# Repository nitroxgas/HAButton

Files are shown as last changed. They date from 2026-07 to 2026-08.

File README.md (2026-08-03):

# HAButton

A quick project designed to repurpose used vapes into something useful: sending events to Home Assistant. It uses a small microcontroller powered by the vape's circuitry to monitor three mechanical switches. When one or more buttons are pressed, the device wakes up, connects to Wi-Fi, and publishes its status via MQTT. Home Assistant automatically recognizes the device and can be programmed to trigger automations based on the event data.
This is a quick weekend project—a first version with plenty of room for improvement.

**Docs:** [English](DOC/en/README.md) · [Português](DOC/README.md)

Build with Cursor, Grok-4.5 and PlatformIO - Firmware for **ESP32-C3 Super Mini**: 3 switches, awake session, MQTT gestures (Home Assistant), OTA, and LED effect pin.

--- 
<p align="center">
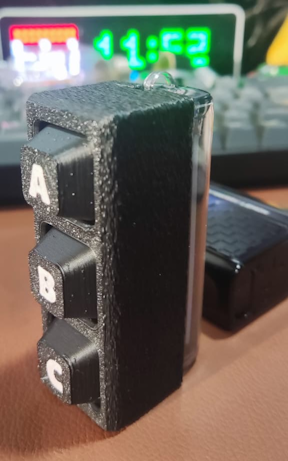
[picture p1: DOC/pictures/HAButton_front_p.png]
Front
  
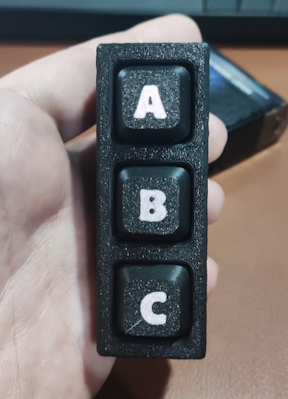
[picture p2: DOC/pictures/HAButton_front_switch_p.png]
Switchs
  
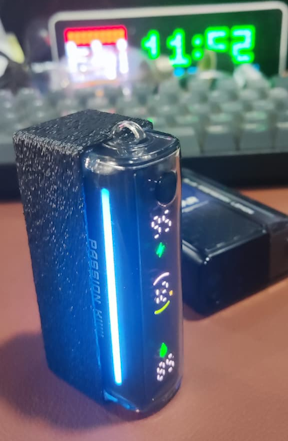
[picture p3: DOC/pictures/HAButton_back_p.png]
Back
  
</p>

## Quick start

```bash
pio run
pio run -t upload
pio device monitor
```

- Portal: hold **A+B+C ~10 s** → AP `HAButton-XXXX`
- Default idle: **20 s** (restarts on each gesture)
- OTA: [English](DOC/en/ota.md) · [Português](DOC/ota.md)
- Full documentation: [English](DOC/en/README.md) · [Português](DOC/README.md)

## Hardware (summary)

| Function | GPIO |
|---|---|
| Buttons A/B/C | 4 / 5 / 3 |
| Effect LED | 7 (PWM ~2.5 V) |
| Status LED | 8 |

Firmware version: **1.4.2** (`include/config.h`)
---
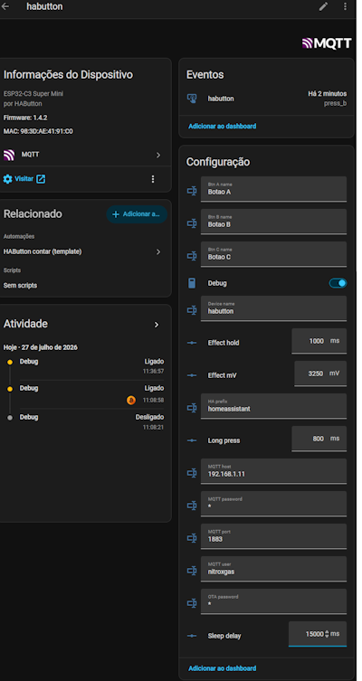
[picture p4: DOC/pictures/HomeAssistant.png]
Home Assistant

---

## Português

Firmware PlatformIO para **ESP32-C3 Super Mini**: 3 switches, sessão acordada, gestos MQTT (Home Assistant), OTA e pino de efeito LED.

Documentação completa: [DOC/README.md](DOC/README.md).

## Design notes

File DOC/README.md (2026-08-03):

# Documentação HAButton

**Idioma:** [Português](README.md) · [English](en/README.md)

Projeto rápido, feito para aproveitar vaporizadores usados, para algo útil - Enviar eventos para um Home Assistant; Ele usa um pequeno microcontrolador alimentado pelo circuito do vaporizador e monitora 3 switchs mecânicos. 
Quando pressionado um ou mais botões o dispositivo acorda, conecta no wifi e publica o estado em um MQTT; 
O Home Assistant por sua vez reconhece automaticamente este dispositivo e pode ser programado para fazer automações com as informações dos eventos; 

Projeto rápido de final de semana, primeira versão, ainda muito a melhorar; 

Faça um parecido para os vaporizadores que conseguir obter, melhor forma de reaproveitar o lixo eletrônico que eles produzem.

O projeto alimenta um ESP32-C3 com os fios destinados ao sensor de pressão do vape. Opcionalmente utiliza o fio de retorno do sensor para informar o uso ao vape, caso ele tenha algum display ou led de animação na sua estrutura.

Uso os GPIOs do ESP32-C3 que monitoram interrupção para tirar o dispositivo do estado de deepsleep e executar o envio de eventos via MQTT;

Para os switchs uso 3 mecanicos padrão;

No primeiro boot o dispositivo inicializa um Access Point para receber as primeiras configurações de wifi e etc. Após conectar no WIFI e publicar os dados no MQTT de um Home Assistant, as configurações podem ser realizadas diretamente na interface. 
Lembre-se que é necessário "acordar" o dispositivo para ele receber alterações de configuração via MQTT;

Atualização via OTA simples, para ser possível o desenvolvimento e implementação usando a alimentação via vape. 

### **NUNCA LIGUE NA USB COM A ALIMENTAÇÃO PELA BATERIA DO VAPE JÁ INSTALADA, PODE DANIFICAR SEU USB**;

Você vai precisar:
 Vape usado e desmontado. **Cuidado neste processo de desmontagem, recomendo uso de luvas e óculos de proteção e descarte imediato dos componentes umidos, contém nicotina que irrita a pele e etc.** Neste caso usei um G30k-Pro, mas quase todos funcionam da mesma forma, lendo um sensor de pressão e alimentando resistências para gerar vapor;
 ESP32-C3 Super Mini;
 3 Switchs mecanicos, ou qualquer outro botão que tiver disponível;
 Fios e etc para as ligações;
 E um case, neste caso modelei um simples e imprimi em 3D; Disponível em: [MakerWorld](https://makerworld.com/en/models/3101722-habutton-g30kpro-case#profileId-3496295) ou [.3mf Neste Repositório](../DOC/pictures/habutton_G30kpro.3mf)

==Projeto feito usando Cursor e Grok-4.5 High Fast;== Sim, porque é um projeto rápido e IA é ótima para isto atualmente;

## Objetivo

Dispositivo com bateria e botões: acorda, mantém sessão (idle 20 s), publica gestos MQTT com discovery HA, OTA na LAN, efeito PWM no GPIO7 durante o envio, e volta ao deep sleep.

| Documento | Conteúdo |
|---|---|
| [arquitetura.md](arquitetura.md) | Sessão acordada, módulos, MQTT |
| [hardware.md](hardware.md) | Pinout A/B/C, efeito GPIO7, portal |
| [configuracao.md](configuracao.md) | Portal, sleep 20s, event_types |
| [mqtt-topicos.md](mqtt-topicos.md) | Todos os tópicos MQTT (runtime + discovery) |
| [mqtt-config.md](mqtt-config.md) | Debug logs + config remota via MQTT/HA |
| [homeassistant-contadores.md](homeassistant-contadores.md) | Contadores/automações: UI ou packages YAML |
| [homeassistant-fallback-yaml.md](homeassistant-fallback-yaml.md) | YAML se discovery falhar |
| [desenvolvimento.md](desenvolvimento.md) | Build USB e overview |
| [ota.md](ota.md) | Guia completo de update OTA |

Home Assistant

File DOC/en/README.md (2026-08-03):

# HAButton Documentation (English)

**Language:** [English](README.md) · [Português](../README.md)

A quick project designed to repurpose used vapes into something useful: sending events to Home Assistant. It uses a small microcontroller powered by the vape's circuitry to monitor three mechanical switches. 
When one or more buttons are pressed, the device wakes up, connects to Wi-Fi, and publishes its status via MQTT. 
Home Assistant automatically recognizes the device and can be programmed to trigger automations based on the event data.

This is a quick weekend project—a first version with plenty of room for improvement.

Build a similar one with whatever vapes you can get your hands on; it’s a great way to repurpose the electronic waste they generate.

The project powers an ESP32-C3 using the wires originally intended for the vape's pressure sensor. 
Optionally, it uses the sensor's return wire to signal usage to the vape itself, in case the unit has a display or animated LED.
I use the ESP32-C3's GPIOs configured for interrupts to wake the device from deep sleep and send events via MQTT.
For the switches, I use three standard mechanical ones.
On the first boot, the device starts an Access Point to receive initial Wi-Fi settings and other configurations. Once connected to Wi-Fi and publishing data to Home Assistant via MQTT, settings can be adjusted directly through the interface. 
It supports simple OTA updates, allowing for development and deployment while powered by the vape. 
**Remember, you must "wake up" the device for it to receive configuration changes via MQTT or OTA.**

### **NEVER CONNECT THE USB WHILE THE VAPE POWER IS CONNECTED; THIS COULD DAMAGE YOUR USB PORT.**

You will need:
A used, disassembled vape. Be careful during disassembly— **I recommend wearing gloves and safety goggles and immediately disposing of any wet components, as they contain nicotine that can irritate the skin.** For this build, I used a G30k-Pro, but almost all of them work the same way: reading a pressure sensor and powering heating coils to generate vapor.  
ESP32-C3 Super Mini. 3 mechanical switches (or any other available buttons);  
Wires and other components for the connections;  
And a case—in this instance, I modeled a simple one and 3D printed it; [MakerWorld](https://makerworld.com/en/models/3101722-habutton-g30kpro-case#profileId-3496295) or [.3mf Here](../pictures/habutton_G30kpro.3mf)

Project created using Cursor and Grok-4.5 High Fast; yes, because it’s a quick project, and AI is excellent for this sort of thing nowadays;

## Objective

Battery-powered device with buttons: wakes up, maintains session (20s idle), publishes MQTT gestures with HA discovery, supports LAN OTA updates, triggers a PWM effect on GPIO7 during transmission, and returns to deep sleep.

| Document | Contents |
|---|---|
| [architecture.md](architecture.md) | Awake session, modules, MQTT |
| [hardware.md](hardware.md) | Pinout A/B/C, GPIO7 effect, portal |
| [configuration.md](configuration.md) | Portal, 20 s sleep, event_types |
| [mqtt-topics.md](mqtt-topics.md) | All MQTT topics (runtime + discovery) |
| [mqtt-config.md](mqtt-config.md) | Debug logs + remote config via MQTT/HA |
| [homeassistant-counters.md](homeassistant-counters.md) | Counters/automations: UI or YAML packages |
| [homeassistant-fallback-yaml.md](homeassistant-fallback-yaml.md) | YAML if discovery fails |
| [development.md](development.md) | USB build overview |
| [ota.md](ota.md) | Full OTA update guide |

Home Assistant

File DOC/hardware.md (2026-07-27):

# Hardware

**Idioma:** [Português](hardware.md) · [English](en/hardware.md)

## Placa

**ESP32-C3 Super Mini** (board PlatformIO `esp32-c3-devkitm-1`).

- USB-C para programação (CDC).
- Alimentação: bateria / 3.3 V (gestão de carga fora do escopo).

## Pinout

| Função | GPIO | Observação |
|---|---|---|
| Botão A | **4** | Switch para GND, pull-up; wake deep sleep |
| Botão B | **5** | Switch para GND, pull-up; wake deep sleep |
| Botão C | **3** | Switch para GND, pull-up; wake deep sleep |
| Efeito LED externo | **7** | PWM LEDC ~0→2,5 V durante MQTT (não wake) |
| LED status onboard | **8** | Azul, ativo em LOW (strapping) |
| BOOT (placa) | **9** | Strapping — **não** é GPIO0 |
| GPIO0 | — | **Não usado** pelo HAButton; no C3 **não** é pino de boot |
| Comum | GND | Compartilhado |

### GPIO0 e pinos que podem impedir o boot

No **ESP32 clássico**, o botão BOOT é GPIO0. No **ESP32-C3** isso **não se aplica**.

| Pino | Papel no C3 | Pode impedir app de subir? |
|---|---|---|
| **GPIO0** | IO/RTC/ADC livre | **Não** (não é strapping). HAButton não o usa. |
| **GPIO2** | Strapping | Se LOW no **reset**, boot/flash pode falhar |
| **GPIO8** | Strapping + LED | Evitar puxar LOW no reset (LED onboard ok) |
| **GPIO9** | Strapping = BOOT | Se LOW no **reset** → modo download (firmware **não** roda) |
| GPIO3/4/5 | Botões A/B/C | Não afetam modo de boot; só wake/gestos |
| GPIO7 | Efeito PWM | Não é strapping |

**Hardware:** não ligue switches em GPIO2/8/9. Não segure o botão **BOOT** da placa ao energizar pela bateria.  
No serial, o boot imprime `[boot] niveis GPIO 0=… 2=… 9=…` para conferência.

### Deep sleep (ESP32-C3)

Só **GPIO0–5** (domínio RTC) podem acordar o chip do deep sleep.  
GPIO6+ **não** são válidos como fonte de wake — o log `gpio N is an invalid deep sleep wakeup IO` indica isso.

Evitar strapping para botões: **GPIO2**, **GPIO8**, **GPIO9**.
### Esquema

```
  3V3 (pull-up interno)
        |
     [GPIO4] ---- switch A ---- GND
     [GPIO5] ---- switch B ---- GND
     [GPIO3] ---- switch C ---- GND
     [GPIO7] ---- módulo efeito LED externo
```

## Gestos e portal

Enquanto acordado, o firmware classifica:

- Clique simples / longo (A, B ou C)
- Combos curtos/longos (AB, AC, BC, ABC)

**Portal WiFiManager:** segure **A+B+C ~10 s** (LED pisca) → reinicia no AP `HAButton-XXXX`.

## Sessão acordada

1. Wake por GPIO → Wi‑Fi → MQTT.
2. Fica acordado monitorando botões.
3. Cada gesto → publica MQTT (GPIO7 já ativo desde o press) + **zera** o timer de idle.
4. Sem atividade por `sleep_delay_ms` (default **20 s**) → deep sleep.

## Pino de efeito (GPIO7)

O ESP32-C3 **não tem DAC**. O firmware usa **PWM (LEDC)** com duty equivalente a ~2,5 V (`2500/3300` de 3,3 V).

- Boot / idle / deep sleep: duty 0 (≈ 0 V).
- **Assim que** há wake por GPIO ou um botão é pressionado: GPIO7 vai de 0 → ~2,5 V **de imediato** (PWM, sem rampa).
- Após o publish MQTT: mantém 2,5 V até o envio terminar e no mínimo **0,5 s** → corta a 0 V.

Se o módulo externo precisar de tensão mais “analógica”, use filtro RC (ex.: 1 kΩ + 100 nF) entre GPIO7 e a entrada.

## Alimentação

LiPo + proteção/carga → pino **5V** + **GND** (não use 4,2 V no **3V3**).  
Em deep sleep o consumo é da ordem de µA (depende do regulador).

### Bateria sem USB

O Super Mini usa **USB CDC** como `Serial`. Sem PC conectado, `Serial.print` / `Serial.flush` antigos podiam **travar** o firmware (aparecia “ligado”, LED apagado, botões sem efeito). O firmware atual usa `Serial.setTxTimeoutMs(0)` e não faz `flush` bloqueante.

No boot a bateria: o LED onboard deve **piscar ~30 ms** — se não piscar, o chip não está executando (alimentação/brownout).

Não deixe USB do PC e bateria ligados ao mesmo tempo no Super Mini.

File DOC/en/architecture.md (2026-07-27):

# Architecture

**Language:** [English](architecture.md) · [Português](../arquitetura.md)

## Flow

```mermaid
flowchart TD
  wake[Wake GPIO A/B/C] --> wifi[WiFiManager]
  wifi --> session[Awake session]
  session --> poll[Poll gestures + OTA]
  poll -->|gesture| effect[GPIO7 HIGH ~2.5V]
  effect --> mqtt[Publish event_type]
  mqtt --> hold[Hold >= 0.5s]
  hold --> off[GPIO7 = 0V]
  off --> reset[Reset idle timer]
  reset --> poll
  poll -->|A+B+C 10s| portal[force_portal + restart]
  poll -->|idle expired| sleep[Deep sleep]
```

## Modules

| File | Role |
|---|---|
| `src/main.cpp` | Awake session, idle timer, OTA/MQTT/effect orchestration |
| `src/buttons.cpp` | A/B/C gesture poll + config chord |
| `src/wifi_setup.cpp` | WiFiManager, NVS, force_portal |
| `src/mqtt_ha.cpp` | Discovery + `event` publish |
| `src/ota_update.cpp` | ArduinoOTA |
| `src/effect_out.cpp` | GPIO7 PWM on/off ~2.5 V (hold ≥0.5 s) |
| `src/status_led.cpp` | Onboard LED GPIO8 |

## NVS persistence (`habutton`)

MQTT, names, `sleep_delay`, `ota_pass`, `force_portal`, `disc_done`.

## MQTT

- Discovery: `homeassistant/event/{deviceId}/config` (retained), with IP in `configuration_url` / `connections`.
- State: `{device}/{mac}/event` with `{"event_type":"..."}`.
- Config entities (switch/number/text) via classic discovery + `{base}/…/set` while awake.
- Connection stays up during the session; discovery is republished if config changes.

## Power / effect

- Effect only during MQTT publish.
- Deep sleep after idle; wake on GPIO4|5|3 low (only GPIO0–5 on C3).

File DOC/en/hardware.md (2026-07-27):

# Hardware

**Language:** [English](hardware.md) · [Português](../hardware.md)

## Board

**ESP32-C3 Super Mini** (PlatformIO board `esp32-c3-devkitm-1`).

- USB-C for programming (CDC).
- Power: battery / 3.3 V (charge management out of scope).

## Pinout

| Function | GPIO | Notes |
|---|---|---|
| Button A | **4** | Switch to GND, pull-up; deep-sleep wake |
| Button B | **5** | Switch to GND, pull-up; deep-sleep wake |
| Button C | **3** | Switch to GND, pull-up; deep-sleep wake |
| External effect LED | **7** | LEDC PWM ~0→2.5 V during MQTT (not wake) |
| Onboard status LED | **8** | Blue, active LOW (strapping) |
| BOOT (board) | **9** | Strapping — **not** GPIO0 |
| GPIO0 | — | **Unused** by HAButton; on C3 it is **not** the boot pin |
| Common | GND | Shared |

### GPIO0 and pins that can block boot

On classic **ESP32**, BOOT is GPIO0. On **ESP32-C3** that does **not** apply.

| Pin | Role on C3 | Can prevent app boot? |
|-----|---|---|
| **GPIO0** | Free IO/RTC/ADC | **No** (not strapping). HAButton does not use it. |
| **GPIO2** | Strapping | If LOW at **reset**, boot/flash may fail |
| **GPIO8** | Strapping + LED | Avoid pulling LOW at reset (onboard LED is fine) |
| **GPIO9** | Strapping = BOOT | If LOW at **reset** → download mode (firmware **does not** run) |
| GPIO3/4/5 | Buttons A/B/C | Do not affect boot mode; only wake/gestures |
| GPIO7 | Effect PWM | Not strapping |

**Hardware:** do not wire switches to GPIO2/8/9. Do not hold the board **BOOT** button when powering from battery.  
On serial, boot prints `[boot] niveis GPIO 0=… 2=… 9=…` for verification.

### Deep sleep (ESP32-C3)

Only **GPIO0–5** (RTC domain) can wake the chip from deep sleep.  
GPIO6+ are **not** valid wake sources — the log `gpio N is an invalid deep sleep wakeup IO` means that.

Avoid strapping pins for buttons: **GPIO2**, **GPIO8**, **GPIO9**.

### Schematic

```
  3V3 (internal pull-up)
        |
     [GPIO4] ---- switch A ---- GND
     [GPIO5] ---- switch B ---- GND
     [GPIO3] ---- switch C ---- GND
     [GPIO7] ---- external effect LED module
```

## Gestures and portal

While awake, firmware classifies:

- Short / long press (A, B, or C)
- Short / long combos (AB, AC, BC, ABC)

**WiFiManager portal:** hold **A+B+C ~10 s** (LED blinks) → restarts on AP `HAButton-XXXX`.

## Awake session

1. GPIO wake → Wi‑Fi → MQTT.
2. Stays awake polling buttons.
3. Each gesture (including wake) → identify → GPIO7 ON → MQTT → GPIO7 OFF → **reset** idle.
4. No activity for `sleep_delay_ms` (default **20 s**) → deep sleep.

## Effect pin (GPIO7)

ESP32-C3 has **no DAC**. Firmware uses **PWM (LEDC)** with duty ≈ 2.5 V (`2500/3300` of 3.3 V).

- Boot / idle / deep sleep: duty 0 (≈ 0 V).
- On GPIO wake or button press: GPIO7 goes 0 → ~2.5 V **immediately** (PWM, no ramp).
- After MQTT publish: holds 2.5 V until send completes and at least **0.5 s** → cuts to 0 V.

If the external module needs a smoother analog voltage, add an RC filter (e.g. 1 kΩ + 100 nF) between GPIO7 and the input.

## Power

LiPo + protection/charger → **5V** pin + **GND** (do not feed 4.2 V into **3V3**).  
In deep sleep, current is on the order of µA (depends on the regulator).

### Battery without USB

Super Mini uses **USB CDC** as `Serial`. Without a PC, older `Serial.print` / `Serial.flush` could **hang** the firmware (looked “on”, LED off, buttons dead). Current firmware uses `Serial.setTxTimeoutMs(0)` and avoids blocking flush.

On battery boot: onboard LED should **blink ~30 ms** — if it does not, the chip is not running (power/brownout).

Do not leave PC USB and battery connected at the same time on the Super Mini.

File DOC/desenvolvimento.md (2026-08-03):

# Desenvolvimento

**Idioma:** [Português](desenvolvimento.md) · [English](en/development.md)

## Build / upload USB

```bash
pio run
pio run -t upload
pio device monitor
```

Environment: `esp32-c3-supermini`. Partições: `min_spiffs.csv` (dual OTA).

## OTA (rede local)

Instruções detalhadas (passo a passo, PlatformIO, troubleshooting): **[ota.md](ota.md)**.

Resumo: acorde o device → mesma LAN →  
`pio run -e esp32-c3-ota -t upload --upload-port <IP>`

## Firmware

Versão: `FW_VERSION` em `include/config.h` (atual **1.4.5**).

## Troubleshooting

| Sintoma | Ação |
|---|---|
| HA sem device | ACL `homeassistant/#`; Serial `VERIFY` |
| OTA timeout | Device acordado? Mesma rede? Senha/IP corretos? |
| Efeito LED fraco/estranho | PWM ~2,5 V; filtro RC se precisar analógico |
| Portal | Segurar A+B+C 10 s |

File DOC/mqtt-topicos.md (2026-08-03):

# Tópicos MQTT

**Idioma:** [Português](mqtt-topicos.md) · [English](en/mqtt-topics.md)

Base: `{device_name}/{mac12}` — ex. `habutton/983dae4191c0`  
Discovery event: `homeassistant/event/{device_name}_{mac12}/config`  
Schema discovery: **10** (clássico + birth `homeassistant/status` para republicar após restart do HA).

---

## Runtime

| Tópico | Dir. | Retain | Payload | Função |
|---|---|---|---|---|
| `{base}/event` | → | não | `{"event_type":"press_a"}` | Gesto |
| `{base}/log` | → | não | JSON debug | Log (se Debug ON) |
| `{base}/config` | → | sim | JSON snapshot | Snapshot |
| `{base}/config/set` | ← | não | JSON | Batch config |
| `{base}/debug` `/set` | ↔ | estado sim | `ON` / `OFF` | Debug |
| `{base}/effect_mirror` `/set` | ↔ | estado sim | `ON` / `OFF` | Espelho LED→GPIO7 |
| `{base}/sleep_delay` `/set` | ↔ | estado sim | ms | Sleep idle |
| `{base}/long_press` `/set` | ↔ | estado sim | ms | Long press |
| `{base}/effect_hold` `/set` | ↔ | estado sim | ms | Effect hold |
| `{base}/effect_mv` `/set` | ↔ | estado sim | mV | Effect alvo |
| `{base}/btn_a_name` `/set` (e B/C) | ↔ | estado sim | texto | Nomes botões |
| `{base}/device_name` `/set` | ↔ | estado sim | texto | Device name |
| `{base}/ota_pass` `/set` | ↔ | estado `*` | texto | OTA password |
| `{base}/mqtt_host` `/port` `/user` `/pass` `/prefix` + `/set` | ↔ | estado sim | MQTT | Broker |

Subscribe no ESP: `{base}/+/set` + `homeassistant/status` (birth do HA → rediscover).  
Só enquanto acordado.

### Gestos em `{base}/event`

JSON: `{"event_type":"press_a"}` (também `long_*`, combos `press_ab`, …).

### `{base}/config/set` (exemplo)

```json
{"debug":true,"sleep_delay_ms":60000,"long_press_ms":900}
```

---

## Entidades no Home Assistant (discovery clássico)

| Entidade | Tipo | unique_id |
|---|---|---|
| Event (gestos) | `event` | `{id}_event` |
| Debug | `switch` | `{id}_debug` |
| Sleep / Long press / Effect hold / Effect mV | `number` | `{id}_sleep_delay` etc. |
| Nomes / OTA / MQTT | `text` | `{id}_btn_a_name` etc. |

Configs com `entity_category: config`. Senhas no estado aparecem como `*`.

---

## Fluxo gesto

1. Identifica botão → 2. GPIO7 ON → 3. publica `{base}/event` → 4. hold → 5. GPIO7 OFF → 6. idle

Detalhes: [mqtt-config.md](mqtt-config.md).

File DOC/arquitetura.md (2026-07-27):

# Arquitetura

**Idioma:** [Português](arquitetura.md) · [English](en/architecture.md)

## Fluxo

```mermaid
flowchart TD
  wake[Wake GPIO A/B/C] --> wifi[WiFiManager]
  wifi --> session[Sessao acordada]
  session --> poll[Poll gestos + OTA]
  poll -->|gesto| effect[GPIO7 HIGH ~2.5V]
  effect --> mqtt[Publish event_type]
  mqtt --> hold[Hold >= 0.5s]
  hold --> off[GPIO7 = 0V]
  off --> reset[Reset idle timer]
  reset --> poll
  poll -->|A+B+C 10s| portal[force_portal + restart]
  poll -->|idle esgotado| sleep[Deep sleep]
```

## Módulos

| Arquivo | Função |
|---|---|
| `src/main.cpp` | Sessão acordada, idle timer, orquestra OTA/MQTT/efeito |
| `src/buttons.cpp` | Poll de gestos A/B/C + config chord |
| `src/wifi_setup.cpp` | WiFiManager, NVS, force_portal |
| `src/mqtt_ha.cpp` | Discovery + publish `event` |
| `src/ota_update.cpp` | ArduinoOTA |
| `src/effect_out.cpp` | PWM GPIO7 on/off ~2,5 V (hold ≥0,5 s) |
| `src/status_led.cpp` | LED onboard GPIO8 |

## Persistência NVS (`habutton`)

MQTT, nomes, `sleep_delay`, `ota_pass`, `force_portal`, `disc_done`.

## MQTT

- Discovery: `homeassistant/event/{deviceId}/config` (retained), com IP em `configuration_url` / `connections`.
- Estado: `{device}/{mac}/event` com `{"event_type":"..."}`.
- Configs (switch/number/text) via discovery clássico + `{base}/…/set` enquanto acordado.
- Conexão mantida durante a sessão; discovery republicado se config mudar.

## Energia / efeito

- Efeito só durante publish MQTT.
- Deep sleep após idle; wake GPIO4|5|3 nível baixo (só GPIO0–5 no C3).

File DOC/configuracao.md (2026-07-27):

# Configuração MQTT / Home Assistant

**Idioma:** [Português](configuracao.md) · [English](en/configuration.md)

## Tópicos MQTT

Lista completa: **[mqtt-topicos.md](mqtt-topicos.md)**.  
Config remota / debug: **[mqtt-config.md](mqtt-config.md)**.

## Contadores e automações no Home Assistant

Guia completo — **UI** (Helpers + colar no editor) e **arquivos** (`packages/habutton.yaml`):  
**[homeassistant-contadores.md](homeassistant-contadores.md)**

## Sessão acordada e sleep

Após conectar, o device fica **acordado** (default **20 s** de idle).

- Cada gesto publicado **reinicia** o timer.
- Campo portal: **Sleep delay ms (idle / OTA)** — default `20000`.

## Tópicos

| Tipo | Exemplo | Retained |
|---|---|---|
| Discovery | `homeassistant/event/habutton_<mac>/config` | sim |
| Evento | `habutton/<mac>/event` | não |

Payload evento: `{"event_type":"press_a"}` (ou `long_b`, `press_ab`, `press_abc`, etc.).

No discovery, o bloco `device` inclui IP local:
- `configuration_url`: `http://<IP>` (link no device no HA)
- `connections`: `["mac", …]` e `["ip", "<IP>"]`

### event_types

`press_a`, `press_b`, `press_c`, `long_a`, `long_b`, `long_c`,  
`press_ab`, `press_ac`, `press_bc`, `press_abc`,  
`long_ab`, `long_ac`, `long_bc`, `long_abc`

Uma única entidade `event` no device HA.

## Portal WiFiManager

| Campo | Default |
|---|---|
| MQTT Host/Port/User/Pass | ver `config.h` / `secrets.h` |
| HA Discovery Prefix | `homeassistant` |
| Device / Botões A/B/C | `habutton`, nomes amigáveis |
| Sleep delay ms | `20000` |
| OTA Password | `habutton-ota` |
| Debug MQTT logs (0/1) | `0` |
| Long press ms | `800` |
| Effect hold ms (min) | `500` |
| Effect target mV | `2500` |

Config remota pelo HA (switch debug, sleep delay, JSON): **[mqtt-config.md](mqtt-config.md)**.

### Reabrir o portal

Segure **A+B+C ~10 s** → AP `HAButton-XXXX` → `http://192.168.4.1`.

## Discovery / ACL

Broker precisa de WRITE em `homeassistant/#`.  
Serial: `VERIFY ... -> ok`. Fallback YAML: [homeassistant-fallback-yaml.md](homeassistant-fallback-yaml.md).

## Home Assistant — o que esperar

O firmware publica **uma** entidade MQTT Event (`event.habutton_…_event`), não dois botões.

- Domínio **Event** (desde HA **2023.8**). Não precisa de YAML se o discovery funcionar.
- A entidade é **sem estado contínuo**: o “estado” vira um **timestamp** a cada gesto; o tipo fica em **atributos → `event_type`** (`press_a`, `long_b`, …).
- Versões antigas do firmware criavam **2 entidades** (`…_btn_a` / `…_btn_b`) em tópicos diferentes. O firmware **1.3.1+** limpa esses discovery retained e republica o schema novo.

### Se ainda vir 2 botões sem atualizar

1. Flash **1.3.1+** e acorde o device (gesto) — no serial deve aparecer `discovery schema=…` e `CLEAR …/btn_a/config`.
2. Em **Dispositivos e serviços → MQTT → habutton**: remova entidades órfãs `btn_a` / `btn_b` se sobrarem.
3. Confirme em **Ferramentas de desenvolvedor → Estados** a entidade `event.…` e o atributo `event_type` após um clique.
4. No MQTT Explorer: tópico `habutton/<mac>/event` com `{"event_type":"press_a"}` (não retained).

## OTA

Guia completo: **[ota.md](ota.md)**.  
Durante a sessão acordada (e a cada clique que estende o idle) o `ArduinoOTA` fica ativo na LAN.

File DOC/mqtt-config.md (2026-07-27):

# Configuração via MQTT / Home Assistant

**Idioma:** [Português](mqtt-config.md) · [English](en/mqtt-config.md)

Com o device **acordado**, o HA (ou MQTT Explorer) altera configs. O ESP grava na NVS.

## Pelo HA (recomendado)

Após discovery schema **7**, no device MQTT aparecem (discovery clássico por componente):

- Switch **Debug**
- Numbers: **Sleep delay**, **Long press**, **Effect hold**, **Effect mV**
- Texts: nomes dos botões, device name, OTA password, MQTT host/port/user/password, HA prefix

Altere na UI do HA → o ESP recebe em `{base}/…/set`, aplica e republica o estado.

> Só funciona na sessão acordada (após clique). Em deep sleep não há subscribe.

## Por JSON (`{base}/config/set`)

| Chave | Exemplo |
|---|---|
| `debug` | `true` / `false` |
| `sleep_delay_ms` | `20000` |
| `long_press_ms` | `800` |
| `effect_hold_ms` | `500` |
| `effect_target_mv` | `2500` |
| `btn_a_name` / `btn_b_name` / `btn_c_name` | texto |
| `device_name` | texto |
| `ota_pass` | texto |
| `mqtt_host` / `mqtt_port` / `mqtt_user` / `mqtt_pass` / `mqtt_prefix` | broker |

```yaml
alias: HAButton config batch
mode: single
triggers: []
actions:
  - action: mqtt.publish
    data:
      topic: habutton/983dae4191c0/config/set
      payload: '{"debug":true,"sleep_delay_ms":60000,"long_press_ms":900}'
```

## Logs

Com Debug=ON → `{base}/log` com JSON (`event`,`t_ms`,`wake`,`ip`,`rssi`,`heap`,`detail`).

## Limitação

Comandos MQTT só na janela acordada. Mudança de MQTT host/senha força reconnect na mesma sessão.

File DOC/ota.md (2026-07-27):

# Atualização OTA (Over-The-Air)

**Idioma:** [Português](ota.md) · [English](en/ota.md)

O HAButton usa **ArduinoOTA** na rede Wi‑Fi local. O device só aceita upload enquanto está **acordado** (sessão após um clique). Em deep sleep o OTA não responde.

## Pré-requisitos

1. Firmware já gravado via USB pelo menos uma vez (partições dual-OTA: `min_spiffs.csv`).
2. PC e ESP32 na **mesma LAN** (mesmo SSID / VLAN).
3. Device **acordado**:
   - Pressione um botão para acordar.
   - Idle default: **20 s** sem novos cliques → deep sleep.
   - Cada novo gesto **reinicia** o timer.
   - Se um upload OTA estiver em andamento, o timer de idle é **reiniciado automaticamente** até o OTA terminar (o ESP não dorme no meio do processo).
4. Conhecer **IP** ou **hostname** e a **senha OTA**.

### Hostname e senha

| Item | Valor |
|---|---|
| Hostname | `{device_name}-{mac4}{mac5}` em hex minúsculo — ex.: device `habutton`, MAC `…:91:C0` → `habutton-91c0` |
| mDNS | `habutton-91c0.local` (se o Windows resolver mDNS) |
| Senha OTA | Portal **OTA Password** (default `habutton-ota`) |

No Serial Monitor, ao conectar Wi‑Fi, aparece algo como:

```text
[ota] pronto hostname=habutton-91c0
[wifi] conectado SSID=... IP=192.168.1.103 ...
```

Use esse **IP** se `.local` não resolver.

### Estender a janela OTA

No portal WiFiManager (A+B+C ~10 s):

- **Sleep delay ms (idle / OTA)** — aumente (ex. `60000` = 1 min) para ter mais tempo sem precisar clicar durante o upload.

---

## Método 1 — PlatformIO (recomendado)

O `pio run` **não** aceita `--upload-protocol` nem `--upload-flags` (só `--upload-port`).  
O protocolo OTA está no env **`esp32-c3-ota`** do `platformio.ini`.

### Passo a passo

1. Abra o projeto (ex.: `d:\Coding\HAButton`).
2. Acorde o ESP (pressione um botão) e anote o IP no Serial (ou no roteador).
3. No PC, rode **imediatamente** (ainda na janela idle):

```bash
cd d:\Coding\HAButton
pio run -e esp32-c3-ota -t upload --upload-port 192.168.1.103
```

Substitua o IP. A senha padrão do env é `habutton-ota`.

Alternativa com hostname (se mDNS funcionar):

```bash
pio run -e esp32-c3-ota -t upload --upload-port habutton-91c0.local
```

4. No Serial do ESP deve aparecer `[ota] start`, progresso e `[ota] end`. O device reinicia com o novo firmware.

### Senha OTA diferente

Edite em `platformio.ini` (env `esp32-c3-ota`):

```ini
upload_flags =
    --auth=sua-senha
```

### Upload USB (padrão)

O env `esp32-c3-supermini` continua com USB/`esptool`:

```bash
pio run -e esp32-c3-supermini -t upload --upload-port COM4
```

---

## Método 2 — Python `espota.py` (PlatformIO)

Com o firmware já compilado:

```bash
pio run
python %USERPROFILE%\.platformio\packages\framework-arduinoespressif32\tools\espota.py -i 192.168.1.103 -a habutton-ota -f .pio\build\esp32-c3-supermini\firmware.bin
```

(No Linux/macOS o caminho do `espota.py` fica sob `~/.platformio/packages/...`.)

---

## Sequência prática (checklist)

1. [ ] Compilar: `pio run`
2. [ ] Aumentar sleep delay no portal se o upload for lento (opcional)
3. [ ] Pressionar botão no HAButton (acordar)
4. [ ] Confirmar no Serial: `[ota] pronto hostname=...` e IP
5. [ ] Enviar OTA: `pio run -e esp32-c3-ota -t upload --upload-port <IP>`
6. [ ] Aguardar reboot; validar versão / comportamento

Dica: mantenha um dedo no botão e clique de novo se o idle estiver perto de expirar **antes** de iniciar o upload (não clique no meio do transfer).

---

## Troubleshooting

| Sintoma | Causa provável | O que fazer |
|---|---|---|
| `No such option: --upload-protocol` | Flag inválida no `pio run` | Use `-e esp32-c3-ota` (Método 1) |
| `No response` / timeout | Device dormindo | Acordar com botão; aumentar sleep delay; repetir upload rápido |
| `Authentication Failed` | Senha errada | Conferir portal e `upload_flags` no ini |
| Host não resolve (`.local`) | mDNS no Windows | Usar o **IP** numérico |
| PC e ESP em redes diferentes | Wi‑Fi guest / VLAN | Mesmo SSID / mesma subnet |
| Upload USB ok, OTA não | Partição sem OTA | Gravar USB com este projeto (`min_spiffs.csv`) |
| OTA inicia e falha no meio | Idle expirou / Wi‑Fi fraco | Sleep delay maior; aproximar do AP |

Códigos de erro ArduinoOTA no Serial (`[ota] error N`):

| Código | Significado |
|---|---|
| 0 | OTA_AUTH_ERROR — senha |
| 1 | OTA_BEGIN_ERROR |
| 2 | OTA_CONNECT_ERROR |
| 3 | OTA_RECEIVE_ERROR |
| 4 | OTA_END_ERROR |

---

## Primeira gravação (USB)

OTA **não** substitui a primeira flash. Use cabo USB-C:

```bash
pio run -e esp32-c3-supermini -t upload --upload-port COMx
```

Depois disso, as atualizações podem ser só por OTA.

## Segurança

- Troque a senha OTA padrão no portal em redes compartilhadas.
- OTA só na LAN; não exponha a porta na internet.
- A senha fica na NVS do ESP (mesmo namespace da config Wi‑Fi/MQTT).

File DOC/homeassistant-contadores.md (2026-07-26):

# Contadores de cliques no Home Assistant

Com a entidade única `event` do HAButton, conte por `event_type`.

## Fluxo

```mermaid
flowchart LR
  esp[ESP event_type] --> evt[event.habutton]
  evt --> auto[Automacao]
  auto --> ctr[counter]
  ctr --> tpl[sensor total_increasing]
  tpl --> um[utility_meter hora/dia/semana/mes]
```

## 1) Counter (exemplo: press_a)

Helper → Contador → `counter.habutton_press_a`.

## 2) Automação

```yaml
automation:
  - id: habutton_count_press_a
    alias: "HAButton contar press_a"
    mode: queued
    trigger:
      - platform: state
        entity_id: event.habutton
    condition:
      - condition: template
        value_template: "{{ trigger.to_state.attributes.event_type == 'press_a' }}"
    action:
      - action: counter.increment
        target:
          entity_id: counter.habutton_press_a
```

Repita para `press_b`, `long_a`, `press_ab`, etc., conforme necessário.

> O `entity_id` real pode variar (`event.habutton_<mac>_event`). Confira em **Entidades**.

## 3) Template + Utility Meter

```yaml
template:
  - sensor:
      - name: "HAButton press_a total"
        unique_id: habutton_press_a_total
        state: "{{ states('counter.habutton_press_a') | int(0) }}"
        state_class: total_increasing
        unit_of_measurement: "cliques"

utility_meter:
  habutton_press_a_hourly:
    source: sensor.habutton_press_a_total
    cycle: hourly
  habutton_press_a_daily:
    source: sensor.habutton_press_a_total
    cycle: daily
  habutton_press_a_weekly:
    source: sensor.habutton_press_a_total
    cycle: weekly
  habutton_press_a_monthly:
    source: sensor.habutton_press_a_total
    cycle: monthly
```

## event_types disponíveis

`press_a/b/c`, `long_a/b/c`, `press_ab/ac/bc/abc`, `long_ab/ac/bc/abc`.

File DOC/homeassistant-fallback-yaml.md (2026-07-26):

# Fallback YAML (sem discovery)

Se o discovery em `homeassistant/event/.../config` não aparecer (ACL), use:

```yaml
mqtt:
  - event:
      name: "habutton"
      unique_id: "habutton_983dae4191c0_event"
      state_topic: "habutton/983dae4191c0/event"
      device_class: button
      event_types:
        - press_a
        - press_b
        - press_c
        - long_a
        - long_b
        - long_c
        - press_ab
        - press_ac
        - press_bc
        - press_abc
        - long_ab
        - long_ac
        - long_bc
        - long_abc
      device:
        identifiers:
          - "habutton_983dae4191c0"
        name: "habutton"
        manufacturer: "HAButton"
        model: "ESP32-C3 Super Mini"
```

Ajuste o MAC. Depois: verificar YAML + reiniciar HA.

Libere ACL `homeassistant/#` para voltar ao discovery automático.

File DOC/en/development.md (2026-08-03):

# Development

**Language:** [English](development.md) · [Português](../desenvolvimento.md)

## USB build / upload

```bash
pio run
pio run -t upload
pio device monitor
```

Environment: `esp32-c3-supermini`. Partitions: `min_spiffs.csv` (dual OTA).

## OTA (local network)

Detailed steps (walkthrough, PlatformIO, troubleshooting): **[ota.md](ota.md)**.

Summary: wake the device → same LAN →  
`pio run -e esp32-c3-ota -t upload --upload-port <IP>`

## Firmware

Version: `FW_VERSION` in `include/config.h` (current **1.4.5**).

## Troubleshooting

| Symptom | Action |
|---|---|
| HA has no device | ACL `homeassistant/#`; Serial `VERIFY` |
| OTA timeout | Device awake? Same network? Correct password/IP? |
| Weak/odd effect LED | PWM ~2.5 V; RC filter if you need analog |
| Portal | Hold A+B+C 10 s |

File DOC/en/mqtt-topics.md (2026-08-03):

# MQTT topics

**Language:** [English](mqtt-topics.md) · [Português](../mqtt-topicos.md)

Base: `{device_name}/{mac12}` — e.g. `habutton/983dae4191c0`  
Event discovery: `homeassistant/event/{device_name}_{mac12}/config`  
Discovery schema: **10** (classic + birth `homeassistant/status` to republish after HA restart).

---

## Runtime

| Topic | Dir. | Retain | Payload | Role |
|---|---|---|---|---|
| `{base}/event` | → | no | `{"event_type":"press_a"}` | Gesture |
| `{base}/log` | → | no | debug JSON | Log (if Debug ON) |
| `{base}/config` | → | yes | JSON snapshot | Snapshot |
| `{base}/config/set` | ← | no | JSON | Batch config |
| `{base}/debug` `/set` | ↔ | state yes | `ON` / `OFF` | Debug |
| `{base}/effect_mirror` `/set` | ↔ | state yes | `ON` / `OFF` | Mirror LED→GPIO7 |
| `{base}/sleep_delay` `/set` | ↔ | state yes | ms | Idle sleep |
| `{base}/long_press` `/set` | ↔ | state yes | ms | Long press |
| `{base}/effect_hold` `/set` | ↔ | state yes | ms | Effect hold |
| `{base}/effect_mv` `/set` | ↔ | state yes | mV | Effect target |
| `{base}/btn_a_name` `/set` (and B/C) | ↔ | state yes | text | Button names |
| `{base}/device_name` `/set` | ↔ | state yes | text | Device name |
| `{base}/ota_pass` `/set` | ↔ | state `*` | text | OTA password |
| `{base}/mqtt_host` `/port` `/user` `/pass` `/prefix` + `/set` | ↔ | state yes | MQTT | Broker |

ESP subscribe: `{base}/+/set` + `homeassistant/status` (HA birth → rediscover).  
Only while awake.

### Gestures on `{base}/event`

JSON: `{"event_type":"press_a"}` (also `long_*`, combos `press_ab`, …).

### `{base}/config/set` (example)

```json
{"debug":true,"sleep_delay_ms":60000,"long_press_ms":900}
```

---

## Home Assistant entities (classic discovery)

| Entity | Type | unique_id |
|---|---|---|
| Event (gestures) | `event` | `{id}_event` |
| Debug | `switch` | `{id}_debug` |
| Sleep / Long press / Effect hold / Effect mV | `number` | `{id}_sleep_delay` etc. |
| Names / OTA / MQTT | `text` | `{id}_btn_a_name` etc. |

Configs use `entity_category: config`. Passwords appear as `*` in state.

---

## Gesture flow

1. Identify button → 2. GPIO7 ON → 3. publish `{base}/event` → 4. hold → 5. GPIO7 OFF → 6. idle

Details: [mqtt-config.md](mqtt-config.md).

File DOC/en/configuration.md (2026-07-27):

# MQTT / Home Assistant configuration

**Language:** [English](configuration.md) · [Português](../configuracao.md)

## MQTT topics

Full list: **[mqtt-topics.md](mqtt-topics.md)**.  
Remote config / debug: **[mqtt-config.md](mqtt-config.md)**.

## Counters and automations in Home Assistant

Full guide — **UI** (Helpers + paste into editor) and **files** (`packages/habutton.yaml`):  
**[homeassistant-counters.md](homeassistant-counters.md)**

## Awake session and sleep

After connecting, the device stays **awake** (default **20 s** idle).

- Each published gesture **restarts** the timer.
- Portal field: **Sleep delay ms (idle / OTA)** — default `20000`.

## Topics

| Type | Example | Retained |
|---|---|---|
| Discovery | `homeassistant/event/habutton_<mac>/config` | yes |
| Event | `habutton/<mac>/event` | no |

Event payload: `{"event_type":"press_a"}` (or `long_b`, `press_ab`, `press_abc`, etc.).

In discovery, the `device` block includes local IP:
- `configuration_url`: `http://<IP>` (link on the HA device)
- `connections`: `["mac", …]` and `["ip", "<IP>"]`

### event_types

`press_a`, `press_b`, `press_c`, `long_a`, `long_b`, `long_c`,  
`press_ab`, `press_ac`, `press_bc`, `press_abc`,  
`long_ab`, `long_ac`, `long_bc`, `long_abc`

A single `event` entity on the HA device.

## WiFiManager portal

| Field | Default |
|---|---|
| MQTT Host/Port/User/Pass | see `config.h` / `secrets.h` |
| HA Discovery Prefix | `homeassistant` |
| Device / Buttons A/B/C | `habutton`, friendly names |
| Sleep delay ms | `20000` |
| OTA Password | `habutton-ota` |
| Debug MQTT logs (0/1) | `0` |
| Long press ms | `800` |
| Effect hold ms (min) | `500` |
| Effect target mV | `2500` |

Remote config from HA (debug switch, sleep delay, JSON): **[mqtt-config.md](mqtt-config.md)**.

### Reopen the portal

Hold **A+B+C ~10 s** → AP `HAButton-XXXX` → `http://192.168.4.1`.

## Discovery / ACL

Broker needs WRITE on `homeassistant/#`.  
Serial: `VERIFY ... -> ok`. YAML fallback: [homeassistant-fallback-yaml.md](homeassistant-fallback-yaml.md).

## Home Assistant — what to expect

Firmware publishes **one** MQTT Event entity (`event.habutton_…_event`), not two buttons.

- **Event** domain (since HA **2023.8**). No YAML needed if discovery works.
- Entity has **no continuous state**: “state” becomes a **timestamp** on each gesture; type is in **attributes → `event_type`** (`press_a`, `long_b`, …).
- Older firmware created **2 entities** (`…_btn_a` / `…_btn_b`) on different topics. Firmware **1.3.1+** clears those retained discoveries and republishes the new schema.

### If you still see 2 buttons without updating

1. Flash **1.3.1+** and wake the device (gesture) — serial should show `discovery schema=…` and `CLEAR …/btn_a/config`.
2. In **Devices & services → MQTT → habutton**: remove orphan `btn_a` / `btn_b` entities if they remain.
3. In **Developer tools → States**, confirm `event.…` and the `event_type` attribute after a click.
4. In MQTT Explorer: topic `habutton/<mac>/event` with `{"event_type":"press_a"}` (not retained).

## OTA

Full guide: **[ota.md](ota.md)**.  
During the awake session (and each click that extends idle) `ArduinoOTA` stays active on the LAN.

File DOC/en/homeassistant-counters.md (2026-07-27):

# Home Assistant — counters and automations

**Language:** [English](homeassistant-counters.md) · [Português](../homeassistant-contadores.md)

Two approaches:

1. **[Via UI](#via-ui-helpers--paste-automation)** — Helpers + paste YAML in the editor (no file editing).
2. **[Via YAML files](#via-yaml-files-packages)** — package in `config/packages/` + include in `configuration.yaml`.

HAButton publishes **one** MQTT Event entity. Each gesture changes the `event_type` attribute.

> Adjust `event.habutton` to the real `entity_id`  
> (**Settings → Devices → habutton**, e.g. `event.habutton_983dae4191c0_event`).

**Do not mix** the same automation created in the UI and in the package (duplicate IDs/aliases). Pick one path.

## event_types

| event_type | Meaning |
|---|---|
| `press_a` / `press_b` / `press_c` | Short press |
| `long_a` / `long_b` / `long_c` | Long press (~≥800 ms) |
| `press_ab` / `press_ac` / `press_bc` / `press_abc` | Short press combo |
| `long_ab` / `long_ac` / `long_bc` / `long_abc` | Long press combo |

## Via UI (Helpers + paste automation)

## Current format (paste in editor)

In recent HA versions, automation YAML uses:

| Old (do not use) | Current (paste in UI) |
|---|---|
| `trigger:` + `platform: state` | `triggers:` + `trigger: state` |
| `condition:` | `conditions:` |
| `action:` / `service:` | `actions:` + `action: domain.service` |
| List under `automation:` in YAML | **One** document (no `automation:` key) |

### How to paste

1. **Settings → Automations & scenes → Create automation → Create new automation**
2. Focus the editor (blank area) and press **Ctrl+V** (Mac: **Cmd+V**), **or**
3. Menu ⋮ → **Edit in YAML** → paste → **Save**

HA converts the pasted YAML to the visual editor.  
Do not edit `automations.yaml` by hand.

---

## 1) Counters (Helpers — no YAML)

For each `event_type` you want to count:

1. **Settings → Devices & services → Helpers → Create helper**
2. Type **Counter**
3. Suggested name: `HAButton press_a` (HA generates `counter.habutton_press_a`)
4. Initial `0`, step `1`

Create all 14 counters (or only the ones you need), with names that result in:

`counter.habutton_<event_type>`  
e.g. `counter.habutton_press_a`, `counter.habutton_long_abc`

---

## 2) Automation — count all events

Paste this into a **new automation** (replace the event `entity_id`):

```yaml
alias: HAButton count all events
description: Increments counter.habutton_<event_type> on each gesture
mode: queued
max: 20
triggers:
  - trigger: state
    entity_id: event.habutton
variables:
  et: "{{ trigger.to_state.attributes.event_type | default('') }}"
  counter_id: "counter.habutton_{{ et }}"
conditions:
  - condition: template
    value_template: "{{ et != '' and states(counter_id) not in ['unknown', 'unavailable', 'none'] }}"
actions:
  - action: counter.increment
    target:
      entity_id: "{{ counter_id }}"
```

Requirements: helpers `counter.habutton_*` already created with the suffix matching `event_type`.

### Variant with `choose` (explicit)

Use if you prefer fixed branches (also paste in the editor):

```yaml
alias: HAButton count (choose)
description: Counts each event_type in its counter
mode: queued
max: 20
triggers:
  - trigger: state
    entity_id: event.habutton
variables:
  et: "{{ trigger.to_state.attributes.event_type | default('') }}"
conditions:
  - condition: template
    value_template: >-
      {{ et in [
        'press_a','press_b','press_c',
        'long_a','long_b','long_c',
        'press_ab','press_ac','press_bc','press_abc',
        'long_ab','long_ac','long_bc','long_abc'
      ] }}
actions:
  - choose:
      - conditions:
          - condition: template
            value_template: "{{ et == 'press_a' }}"
        sequence:
          - action: counter.increment
            target:
              entity_id: counter.habutton_press_a
      - conditions:
          - condition: template
            value_template: "{{ et == 'press_b' }}"
        sequence:
          - action: counter.increment
            target:
              entity_id: counter.habutton_press_b
      - conditions:
          - condition: template
            value_template: "{{ et == 'press_c' }}"
        sequence:
          - action: counter.increment
            target:
              entity_id: counter.habutton_press_c
      - conditions:
          - condition: template
            value_template: "{{ et == 'long_a' }}"
        sequence:
          - action: counter.increment
            target:
              entity_id: counter.habutton_long_a
      - conditions:
          - condition: template
            value_template: "{{ et == 'long_b' }}"
        sequence:
          - action: counter.increment
            target:
              entity_id: counter.habutton_long_b
      - conditions:
          - condition: template
            value_template: "{{ et == 'long_c' }}"
        sequence:
          - action: counter.increment
            target:
              entity_id: counter.habutton_long_c
      - conditions:
          - condition: template
            value_template: "{{ et == 'press_ab' }}"
        sequence:
          - action: counter.increment
            target:
              entity_id: counter.habutton_press_ab
      - conditions:
          - condition: template
            value_template: "{{ et == 'press_ac' }}"
        sequence:
          - action: counter.increment
            target:
              entity_id: counter.habutton_press_ac
      - conditions:
          - condition: template
            value_template: "{{ et == 'press_bc' }}"
        sequence:
          - action: counter.increment
            target:
              entity_id: counter.habutton_press_bc
      - conditions:
          - condition: template
            value_template: "{{ et == 'press_abc' }}"
        sequence:
          - action: counter.increment
            target:
              entity_id: counter.habutton_press_abc
      - conditions:
          - condition: template
            value_template: "{{ et == 'long_ab' }}"
        sequence:
          - action: counter.increment
            target:
              entity_id: counter.habutton_long_ab
      - conditions:
          - condition: template
            value_template: "{{ et == 'long_ac' }}"
        sequence:
          - action: counter.increment
            target:
              entity_id: counter.habutton_long_ac
      - conditions:
          - condition: template
            value_template: "{{ et == 'long_bc' }}"
        sequence:
          - action: counter.increment
            target:
              entity_id: counter.habutton_long_bc
      - conditions:
          - condition: template
            value_template: "{{ et == 'long_abc' }}"
        sequence:
          - action: counter.increment
            target:
              entity_id: counter.habutton_long_abc
```

---

## 3) Automation — actions per gesture

Paste into a **second** automation (independent from the counting one). Replace entities with yours:

```yaml
alias: HAButton gestures → actions
description: Actions per event_type (edit the entities)
mode: queued
max: 20
triggers:
  - trigger: state
    entity_id: event.habutton
variables:
  et: "{{ trigger.to_state.attributes.event_type | default('') }}"
conditions: []
actions:
  - choose:
      - conditions:
          - condition: template
            value_template: "{{ et == 'press_a' }}"
        sequence:
          - action: light.toggle
            target:
              entity_id: light.sala
      - conditions:
          - condition: template
            value_template: "{{ et == 'press_b' }}"
        sequence:
          - action: switch.toggle
            target:
              entity_id: switch.abajur
      - conditions:
          - condition: template
            value_template: "{{ et == 'press_c' }}"
        sequence:
          - action: script.modo_cinema
      - conditions:
          - condition: template
            value_template: "{{ et == 'long_a' }}"
        sequence:
          - action: light.turn_off
            target:
              entity_id: light.sala
      - conditions:
          - condition: template
            value_template: "{{ et == 'long_b' }}"
        sequence:
          - action: scene.turn_on
            target:
              entity_id: scene.noite
      - conditions:
          - condition: template
            value_template: "{{ et == 'long_c' }}"
        sequence:
          - action: lock.lock
            target:
              entity_id: lock.porta
      - conditions:
          - condition: template
            value_template: "{{ et == 'press_ab' }}"
        sequence:
          - action: media_player.media_play_pause
            target:
              entity_id: media_player.tv
      - conditions:
          - condition: template
            value_template: "{{ et == 'press_ac' }}"
        sequence:
          - action: climate.set_temperature
            target:
              entity_id: climate.sala
            data:
              temperature: 22
      - conditions:
          - condition: template
            value_template: "{{ et == 'press_bc' }}"
        sequence:
          - action: cover.toggle
            target:
              entity_id: cover.persiana
      - conditions:
          - condition: template
            value_template: "{{ et == 'press_abc' }}"
        sequence:
          - action: script.cheguei_em_casa
      - conditions:
          - condition: template
            value_template: "{{ et == 'long_ab' }}"
        sequence:
          - action: alarm_control_panel.alarm_arm_home
            target:
              entity_id: alarm_control_panel.casa
      - conditions:
          - condition: template
            value_template: "{{ et == 'long_ac' }}"
        sequence:
          - action: vacuum.start
            target:
              entity_id: vacuum.aspirador
      - conditions:
          - condition: template
            value_template: "{{ et == 'long_bc' }}"
        sequence:
          - action: fan.toggle
            target:
              entity_id: fan.teto
      - conditions:
          - condition: template
            value_template: "{{ et == 'long_abc' }}"
        sequence:
          - action: script.emergencia
```

### Single gesture (minimal)

```yaml
alias: HAButton press_a → toggle light
description: ""
mode: single
triggers:
  - trigger: state
    entity_id: event.habutton
conditions:
  - condition: template
    value_template: "{{ trigger.to_state.attributes.event_type == 'press_a' }}"
actions:
  - action: light.toggle
    target:
      entity_id: light.sala
```

---

## 4) Totals by hour / day / week / month (optional, still in UI)

Without editing files:

1. **Helpers → Create helper → Template**  
   - State: `{{ states('counter.habutton_press_a') | int(0) }}`  
   - State class: **Total increasing** (`total_increasing`)  
   - Unit: `events`
2. **Helpers → Create helper → Utility Meter**  
   - Source: the template sensor above  
   - Cycle: hourly / daily / weekly / monthly  

Repeat only for the gestures that matter.

---

## How to test

1. **Developer tools → States** → `event.…` → `event_type` attribute
2. Trigger a gesture → `counter.habutton_press_a` (etc.) should increment
3. In the automation → **Traces** to see trigger / choose

## Checklist (UI)

- [ ] `event.…` entity visible (MQTT discovery)
- [ ] Counters created via **Helpers** (`counter.habutton_<event_type>`)
- [ ] Counting automation pasted in editor (`triggers` / `actions` format)
- [ ] Actions automation pasted (your entities)
- [ ] (Optional) Template + Utility Meter via Helpers

---

## Via YAML files (packages)

Use when you want to version everything in files or create all 14 counters + meters at once.

### Where files live

Home Assistant configuration folder (same place as `configuration.yaml`):

| Installation | Typical path |
|---|---|
| Home Assistant OS / Supervised | `/config/` (File Editor / Samba / Studio Code Server) |
| Docker container | mounted volume, e.g. `/home/…/homeassistant/` → `/config` |
| Core (venv) | directory passed in `-c` / where `configuration.yaml` lives |

Suggested structure:

```text
config/                          # or /config on HA OS
├── configuration.yaml           # main file (edit)
├── automations.yaml             # managed by UI — do not mix here
└── packages/                    # create this folder
    └── habutton.yaml            # HAButton package (create)
```

### Step 1 — Enable packages in `configuration.yaml`

Open `configuration.yaml` and ensure the `homeassistant:` block includes `packages`.

If `homeassistant:` **already exists**:

```yaml
homeassistant:
  # ... other options you already have (name, unit_system, etc.)
  packages: !include_dir_named packages
```

If `homeassistant:` **does not exist**, add:

```yaml
homeassistant:
  packages: !include_dir_named packages
```

> Indentation: `packages:` must be **2 spaces** inside `homeassistant:`.  
> `!include_dir_named packages` loads each `*.yaml` from the `packages/` folder (the file name becomes the package name).

Also keep the default line for UI automations (do not remove):

```yaml
automation: !include automations.yaml
```

Package automations use a different key (`automation habutton:` below) and coexist with UI ones.

### Step 2 — Create the folder and file

1. Create the `packages` folder next to `configuration.yaml`.
2. Create `packages/habutton.yaml` with the content from the next section.
3. Replace `event.habutton` with the real `entity_id` everywhere.

### Step 3 — Contents of `packages/habutton.yaml`

The package file **does not** repeat the `packages:` key.  
Place domains at the root level, like in `configuration.yaml`.

**MQTT compatibility (firmware ≥ 1.4.2 / schema 7):** the package **does not** reference MQTT topics — only the event `entity_id` and `attributes.event_type`. With the rollback, the contract is again `{base}/event` + `{"event_type":"..."}` and `unique_id` `…_event`. **You do not need to change the package structure**; just verify that `entity_id` still points to the correct entity (e.g. `event.habutton` or `event.habutton_<mac>_event`). If during the broken period HA created `…_e`, update `entity_id` in the package to the restored `…_event` entity.

```yaml
# packages/habutton.yaml
# HAButton package — counters, counting automation, templates and utility_meters.
# Replace event.habutton with the real entity_id.

counter:
  habutton_press_a:
    name: "HAButton press_a"
    initial: 0
    step: 1
  habutton_press_b:
    name: "HAButton press_b"
    initial: 0
    step: 1
  habutton_press_c:
    name: "HAButton press_c"
    initial: 0
    step: 1
  habutton_long_a:
    name: "HAButton long_a"
    initial: 0
    step: 1
  habutton_long_b:
    name: "HAButton long_b"
    initial: 0
    step: 1
  habutton_long_c:
    name: "HAButton long_c"
    initial: 0
    step: 1
  habutton_press_ab:
    name: "HAButton press_ab"
    initial: 0
    step: 1
  habutton_press_ac:
    name: "HAButton press_ac"
    initial: 0
    step: 1
  habutton_press_bc:
    name: "HAButton press_bc"
    initial: 0
    step: 1
  habutton_press_abc:
    name: "HAButton press_abc"
    initial: 0
    step: 1
  habutton_long_ab:
    name: "HAButton long_ab"
    initial: 0
    step: 1
  habutton_long_ac:
    name: "HAButton long_ac"
    initial: 0
    step: 1
  habutton_long_bc:
    name: "HAButton long_bc"
    initial: 0
    step: 1
  habutton_long_abc:
    name: "HAButton long_abc"
    initial: 0
    step: 1

# Labeled key: does not conflict with automation: !include automations.yaml
automation habutton:
  - id: habutton_count_all_events
    alias: "HAButton count all events"
    description: "Increments counter.habutton_<event_type>"
    mode: queued
    max: 20
    triggers:
      - trigger: state
        entity_id: event.habutton
    variables:
      et: "{{ trigger.to_state.attributes.event_type | default('') }}"
      counter_id: "counter.habutton_{{ et }}"
    conditions:
      - condition: template
        value_template: "{{ et != '' and states(counter_id) not in ['unknown', 'unavailable', 'none'] }}"
    actions:
      - action: counter.increment
        target:
          entity_id: "{{ counter_id }}"

  - id: habutton_gestos_acoes
    alias: "HAButton gestures → actions"
    description: "Edit the target entities"
    mode: queued
    max: 20
    triggers:
      - trigger: state
        entity_id: event.habutton
    variables:
      et: "{{ trigger.to_state.attributes.event_type | default('') }}"
    actions:
      - choose:
          - conditions:
              - condition: template
                value_template: "{{ et == 'press_a' }}"
            sequence:
              - action: light.toggle
                target:
                  entity_id: light.sala
          - conditions:
              - condition: template
                value_template: "{{ et == 'press_b' }}"
            sequence:
              - action: switch.toggle
                target:
                  entity_id: switch.abajur
          - conditions:
              - condition: template
                value_template: "{{ et == 'press_c' }}"
            sequence:
              - action: script.modo_cinema
          - conditions:
              - condition: template
                value_template: "{{ et == 'long_a' }}"
            sequence:
              - action: light.turn_off
                target:
                  entity_id: light.sala
          - conditions:
              - condition: template
                value_template: "{{ et == 'long_b' }}"
            sequence:
              - action: scene.turn_on
                target:
                  entity_id: scene.noite
          - conditions:
              - condition: template
                value_template: "{{ et == 'long_c' }}"
            sequence:
              - action: lock.lock
                target:
                  entity_id: lock.porta
          - conditions:
              - condition: template
                value_template: "{{ et == 'press_ab' }}"
            sequence:
              - action: media_player.media_play_pause
                target:
                  entity_id: media_player.tv
          - conditions:
              - condition: template
                value_template: "{{ et == 'press_ac' }}"
            sequence:
              - action: climate.set_temperature
                target:
                  entity_id: climate.sala
                data:
                  temperature: 22
          - conditions:
              - condition: template
                value_template: "{{ et == 'press_bc' }}"
            sequence:
              - action: cover.toggle
                target:
                  entity_id: cover.persiana
          - conditions:
              - condition: template
                value_template: "{{ et == 'press_abc' }}"
            sequence:
              - action: script.cheguei_em_casa
          - conditions:
              - condition: template
                value_template: "{{ et == 'long_ab' }}"
            sequence:
              - action: alarm_control_panel.alarm_arm_home
                target:
                  entity_id: alarm_control_panel.casa
          - conditions:
              - condition: template
                value_template: "{{ et == 'long_ac' }}"
            sequence:
              - action: vacuum.start
                target:
                  entity_id: vacuum.aspirador
          - conditions:
              - condition: template
                value_template: "{{ et == 'long_bc' }}"
            sequence:
              - action: fan.toggle
                target:
                  entity_id: fan.teto
          - conditions:
              - condition: template
                value_template: "{{ et == 'long_abc' }}"
            sequence:
              - action: script.emergencia

template:
  - sensor:
      - name: "HAButton press_a total"
        unique_id: habutton_press_a_total
        state: "{{ states('counter.habutton_press_a') | int(0) }}"
        state_class: total_increasing
        unit_of_measurement: "events"
      - name: "HAButton press_b total"
        unique_id: habutton_press_b_total
        state: "{{ states('counter.habutton_press_b') | int(0) }}"
        state_class: total_increasing
        unit_of_measurement: "events"
      - name: "HAButton press_c total"
        unique_id: habutton_press_c_total
        state: "{{ states('counter.habutton_press_c') | int(0) }}"
        state_class: total_increasing
        unit_of_measurement: "events"
      - name: "HAButton long_a total"
        unique_id: habutton_long_a_total
        state: "{{ states('counter.habutton_long_a') | int(0) }}"
        state_class: total_increasing
        unit_of_measurement: "events"
      - name: "HAButton long_b total"
        unique_id: habutton_long_b_total
        state: "{{ states('counter.habutton_long_b') | int(0) }}"
        state_class: total_increasing
        unit_of_measurement: "events"
      - name: "HAButton long_c total"
        unique_id: habutton_long_c_total
        state: "{{ states('counter.habutton_long_c') | int(0) }}"
        state_class: total_increasing
        unit_of_measurement: "events"
      - name: "HAButton press_ab total"
        unique_id: habutton_press_ab_total
        state: "{{ states('counter.habutton_press_ab') | int(0) }}"
        state_class: total_increasing
        unit_of_measurement: "events"
      - name: "HAButton press_ac total"
        unique_id: habutton_press_ac_total
        state: "{{ states('counter.habutton_press_ac') | int(0) }}"
        state_class: total_increasing
        unit_of_measurement: "events"
      - name: "HAButton press_bc total"
        unique_id: habutton_press_bc_total
        state: "{{ states('counter.habutton_press_bc') | int(0) }}"
        state_class: total_increasing
        unit_of_measurement: "events"
      - name: "HAButton press_abc total"
        unique_id: habutton_press_abc_total
        state: "{{ states('counter.habutton_press_abc') | int(0) }}"
        state_class: total_increasing
        unit_of_measurement: "events"
      - name: "HAButton long_ab total"
        unique_id: habutton_long_ab_total
        state: "{{ states('counter.habutton_long_ab') | int(0) }}"
        state_class: total_increasing
        unit_of_measurement: "events"
      - name: "HAButton long_ac total"
        unique_id: habutton_long_ac_total
        state: "{{ states('counter.habutton_long_ac') | int(0) }}"
        state_class: total_increasing
        unit_of_measurement: "events"
      - name: "HAButton long_bc total"
        unique_id: habutton_long_bc_total
        state: "{{ states('counter.habutton_long_bc') | int(0) }}"
        state_class: total_increasing
        unit_of_measurement: "events"
      - name: "HAButton long_abc total"
        unique_id: habutton_long_abc_total
        state: "{{ states('counter.habutton_long_abc') | int(0) }}"
        state_class: total_increasing
        unit_of_measurement: "events"

utility_meter:
  habutton_press_a_hourly:
    source: sensor.habutton_press_a_total
    cycle: hourly
  habutton_press_a_daily:
    source: sensor.habutton_press_a_total
    cycle: daily
  habutton_press_a_weekly:
    source: sensor.habutton_press_a_total
    cycle: weekly
  habutton_press_a_monthly:
    source: sensor.habutton_press_a_total
    cycle: monthly
  habutton_press_b_hourly:
    source: sensor.habutton_press_b_total
    cycle: hourly
  habutton_press_b_daily:
    source: sensor.habutton_press_b_total
    cycle: daily
  habutton_press_b_weekly:
    source: sensor.habutton_press_b_total
    cycle: weekly
  habutton_press_b_monthly:
    source: sensor.habutton_press_b_total
    cycle: monthly
  habutton_press_c_hourly:
    source: sensor.habutton_press_c_total
    cycle: hourly
  habutton_press_c_daily:
    source: sensor.habutton_press_c_total
    cycle: daily
  habutton_press_c_weekly:
    source: sensor.habutton_press_c_total
    cycle: weekly
  habutton_press_c_monthly:
    source: sensor.habutton_press_c_total
    cycle: monthly
  habutton_long_a_hourly:
    source: sensor.habutton_long_a_total
    cycle: hourly
  habutton_long_a_daily:
    source: sensor.habutton_long_a_total
    cycle: daily
  habutton_long_a_weekly:
    source: sensor.habutton_long_a_total
    cycle: weekly
  habutton_long_a_monthly:
    source: sensor.habutton_long_a_total
    cycle: monthly
  habutton_long_b_hourly:
    source: sensor.habutton_long_b_total
    cycle: hourly
  habutton_long_b_daily:
    source: sensor.habutton_long_b_total
    cycle: daily
  habutton_long_b_weekly:
    source: sensor.habutton_long_b_total
    cycle: weekly
  habutton_long_b_monthly:
    source: sensor.habutton_long_b_total
    cycle: monthly
  habutton_long_c_hourly:
    source: sensor.habutton_long_c_total
    cycle: hourly
  habutton_long_c_daily:
    source: sensor.habutton_long_c_total
    cycle: daily
  habutton_long_c_weekly:
    source: sensor.habutton_long_c_total
    cycle: weekly
  habutton_long_c_monthly:
    source: sensor.habutton_long_c_total
    cycle: monthly
  habutton_press_ab_hourly:
    source: sensor.habutton_press_ab_total
    cycle: hourly
  habutton_press_ab_daily:
    source: sensor.habutton_press_ab_total
    cycle: daily
  habutton_press_ab_weekly:
    source: sensor.habutton_press_ab_total
    cycle: weekly
  habutton_press_ab_monthly:
    source: sensor.habutton_press_ab_total
    cycle: monthly
  habutton_press_ac_hourly:
    source: sensor.habutton_press_ac_total
    cycle: hourly
  habutton_press_ac_daily:
    source: sensor.habutton_press_ac_total
    cycle: daily
  habutton_press_ac_weekly:
    source: sensor.habutton_press_ac_total
    cycle: weekly
  habutton_press_ac_monthly:
    source: sensor.habutton_press_ac_total
    cycle: monthly
  habutton_press_bc_hourly:
    source: sensor.habutton_press_bc_total
    cycle: hourly
  habutton_press_bc_daily:
    source: sensor.habutton_press_bc_total
    cycle: daily
  habutton_press_bc_weekly:
    source: sensor.habutton_press_bc_total
    cycle: weekly
  habutton_press_bc_monthly:
    source: sensor.habutton_press_bc_total
    cycle: monthly
  habutton_press_abc_hourly:
    source: sensor.habutton_press_abc_total
    cycle: hourly
  habutton_press_abc_daily:
    source: sensor.habutton_press_abc_total
    cycle: daily
  habutton_press_abc_weekly:
    source: sensor.habutton_press_abc_total
    cycle: weekly
  habutton_press_abc_monthly:
    source: sensor.habutton_press_abc_total
    cycle: monthly
  habutton_long_ab_hourly:
    source: sensor.habutton_long_ab_total
    cycle: hourly
  habutton_long_ab_daily:
    source: sensor.habutton_long_ab_total
    cycle: daily
  habutton_long_ab_weekly:
    source: sensor.habutton_long_ab_total
    cycle: weekly
  habutton_long_ab_monthly:
    source: sensor.habutton_long_ab_total
    cycle: monthly
  habutton_long_ac_hourly:
    source: sensor.habutton_long_ac_total
    cycle: hourly
  habutton_long_ac_daily:
    source: sensor.habutton_long_ac_total
    cycle: daily
  habutton_long_ac_weekly:
    source: sensor.habutton_long_ac_total
    cycle: weekly
  habutton_long_ac_monthly:
    source: sensor.habutton_long_ac_total
    cycle: monthly
  habutton_long_bc_hourly:
    source: sensor.habutton_long_bc_total
    cycle: hourly
  habutton_long_bc_daily:
    source: sensor.habutton_long_bc_total
    cycle: daily
  habutton_long_bc_weekly:
    source: sensor.habutton_long_bc_total
    cycle: weekly
  habutton_long_bc_monthly:
    source: sensor.habutton_long_bc_total
    cycle: monthly
  habutton_long_abc_hourly:
    source: sensor.habutton_long_abc_total
    cycle: hourly
  habutton_long_abc_daily:
    source: sensor.habutton_long_abc_total
    cycle: daily
  habutton_long_abc_weekly:
    source: sensor.habutton_long_abc_total
    cycle: weekly
  habutton_long_abc_monthly:
    source: sensor.habutton_long_abc_total
    cycle: monthly
```

You can remove from the package the `utility_meter` / `template` / action automations you do not need.

### Step 4 — Validate and apply

1. **Developer tools → YAML → Check configuration**  
   (or **Settings → System → Restart → Quick check**)
2. If OK: **Restart Home Assistant**  
   (packages / `counter` / `template` / `utility_meter` require restart; automation alone sometimes reloads, but restart is the safe path)
3. Check entities: `counter.habutton_press_a`, `sensor.habutton_press_a_total`, `sensor.habutton_press_a_daily`, etc.
4. Package automations appear in **Automations & scenes** (may be read-only in the UI if they come from labeled YAML)

### Alternative without `packages/` folder

Everything in `configuration.yaml` (less organized):

```yaml
homeassistant:
  # ...

counter:
  habutton_press_a:
    name: "HAButton press_a"
    initial: 0
    step: 1
  # ... remaining counters

automation habutton:
  - id: habutton_count_all_events
    alias: "HAButton count all events"
    mode: queued
    triggers:
      - trigger: state
        entity_id: event.habutton
    # ... rest same as package
```

Or a single included file:

```yaml
# configuration.yaml
homeassistant:
  packages:
    habutton: !include packages/habutton.yaml
```

(in this mode the content of `habutton.yaml` is the same as in Step 3.)

### Common conflicts

| Symptom | Cause / fix |
|---|---|
| `packages` integration not found | `packages:` outside `homeassistant:` — indent 2 spaces |
| Entity ID already exists | Counter/helper already created in UI with same id — delete the helper or rename in YAML |
| Duplicate automation | Same `id`/`alias` in UI and package — remove one side |
| Invalid YAML | Indentation; use configuration checker before restart |

### Checklist (files)

- [ ] `packages/` folder created next to `configuration.yaml`
- [ ] `homeassistant: packages: !include_dir_named packages` in `configuration.yaml`
- [ ] `packages/habutton.yaml` with counters + `automation habutton:`
- [ ] `event.habutton` adjusted to the real `entity_id`
- [ ] Configuration checked + Home Assistant restarted
- [ ] No duplicate counters/automations in the UI

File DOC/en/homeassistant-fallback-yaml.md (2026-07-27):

# Fallback YAML (no discovery)

**Language:** [English](homeassistant-fallback-yaml.md) · [Português](../homeassistant-fallback-yaml.md)

If discovery under `homeassistant/event/.../config` does not appear (ACL), use:

```yaml
mqtt:
  - event:
      name: "habutton"
      unique_id: "habutton_983dae4191c0_event"
      state_topic: "habutton/983dae4191c0/event"
      device_class: button
      event_types:
        - press_a
        - press_b
        - press_c
        - long_a
        - long_b
        - long_c
        - press_ab
        - press_ac
        - press_bc
        - press_abc
        - long_ab
        - long_ac
        - long_bc
        - long_abc
      device:
        identifiers:
          - "habutton_983dae4191c0"
        name: "habutton"
        manufacturer: "HAButton"
        model: "ESP32-C3 Super Mini"
```

Adjust the MAC. Then: check YAML + restart HA.

Allow ACL `homeassistant/#` to restore automatic discovery.

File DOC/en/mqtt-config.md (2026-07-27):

# Configuration via MQTT / Home Assistant

**Language:** [English](mqtt-config.md) · [Português](../mqtt-config.md)

With the device **awake**, HA (or MQTT Explorer) can change settings. The ESP stores them in NVS.

## From HA (recommended)

After discovery schema **7**, the MQTT device shows (classic per-component discovery):

- Switch **Debug**
- Numbers: **Sleep delay**, **Long press**, **Effect hold**, **Effect mV**
- Texts: button names, device name, OTA password, MQTT host/port/user/password, HA prefix

Change them in the HA UI → ESP receives `{base}/…/set`, applies, and republishes state.

> Only works during the awake session (after a click). There is no subscribe in deep sleep.

## Via JSON (`{base}/config/set`)

| Key | Example |
|-----|---|
| `debug` | `true` / `false` |
| `sleep_delay_ms` | `20000` |
| `long_press_ms` | `800` |
| `effect_hold_ms` | `500` |
| `effect_target_mv` | `2500` |
| `btn_a_name` / `btn_b_name` / `btn_c_name` | text |
| `device_name` | text |
| `ota_pass` | text |
| `mqtt_host` / `mqtt_port` / `mqtt_user` / `mqtt_pass` / `mqtt_prefix` | broker |

```yaml
alias: HAButton config batch
mode: single
triggers: []
actions:
  - action: mqtt.publish
    data:
      topic: habutton/983dae4191c0/config/set
      payload: '{"debug":true,"sleep_delay_ms":60000,"long_press_ms":900}'
```

## Logs

With Debug=ON → `{base}/log` with JSON (`event`,`t_ms`,`wake`,`ip`,`rssi`,`heap`,`detail`).

## Limitation

MQTT commands only in the awake window. Changing MQTT host/password forces reconnect in the same session.

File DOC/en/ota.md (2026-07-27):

# OTA update (Over-The-Air)

**Language:** [English](ota.md) · [Português](../ota.md)

HAButton uses **ArduinoOTA** on the local Wi‑Fi network. The device only accepts uploads while **awake** (session after a click). In deep sleep OTA does not respond.

## Prerequisites

1. Firmware already flashed via USB at least once (dual-OTA partitions: `min_spiffs.csv`).
2. PC and ESP32 on the **same LAN** (same SSID / VLAN).
3. Device **awake**:
   - Press a button to wake.
   - Default idle: **20 s** with no new clicks → deep sleep.
   - Each new gesture **restarts** the timer.
   - While an OTA upload is in progress, the idle timer is **automatically restarted** until OTA finishes (ESP will not sleep mid-transfer).
4. Know the **IP** or **hostname** and the **OTA password**.

### Hostname and password

| Item | Value |
|---|---|
| Hostname | `{device_name}-{mac4}{mac5}` lowercase hex — e.g. device `habutton`, MAC `…:91:C0` → `habutton-91c0` |
| mDNS | `habutton-91c0.local` (if Windows resolves mDNS) |
| OTA password | Portal **OTA Password** (default `habutton-ota`) |

On Serial Monitor, after Wi‑Fi connects:

```text
[ota] pronto hostname=habutton-91c0
[wifi] conectado SSID=... IP=192.168.1.103 ...
```

Use that **IP** if `.local` does not resolve.

### Extend the OTA window

In the WiFiManager portal (A+B+C ~10 s):

- **Sleep delay ms (idle / OTA)** — increase (e.g. `60000` = 1 min) so you have more time without clicking during upload.

---

## Method 1 — PlatformIO (recommended)

`pio run` does **not** accept `--upload-protocol` or `--upload-flags` (only `--upload-port`).  
OTA protocol is in the **`esp32-c3-ota`** env in `platformio.ini`.

### Steps

1. Open the project (e.g. `d:\Coding\HAButton`).
2. Wake the ESP (press a button) and note the IP from Serial (or your router).
3. On the PC, run **immediately** (still within the idle window):

```bash
cd d:\Coding\HAButton
pio run -e esp32-c3-ota -t upload --upload-port 192.168.1.103
```

Replace the IP. Default env password is `habutton-ota`.

Hostname alternative (if mDNS works):

```bash
pio run -e esp32-c3-ota -t upload --upload-port habutton-91c0.local
```

4. On ESP Serial you should see `[ota] start`, progress, and `[ota] end`. The device reboots with the new firmware.

### Different OTA password

Edit `platformio.ini` (env `esp32-c3-ota`):

```ini
upload_flags =
    --auth=your-password
```

### USB upload (default)

Env `esp32-c3-supermini` still uses USB/`esptool`:

```bash
pio run -e esp32-c3-supermini -t upload --upload-port COM4
```

---

## Method 2 — Python `espota.py` (PlatformIO)

With firmware already built:

```bash
pio run
python %USERPROFILE%\.platformio\packages\framework-arduinoespressif32\tools\espota.py -i 192.168.1.103 -a habutton-ota -f .pio\build\esp32-c3-supermini\firmware.bin
```

(On Linux/macOS, `espota.py` lives under `~/.platformio/packages/...`.)

---

## Practical checklist

1. [ ] Build: `pio run`
2. [ ] Increase sleep delay in the portal if upload is slow (optional)
3. [ ] Press a button on HAButton (wake)
4. [ ] Confirm on Serial: `[ota] pronto hostname=...` and IP
5. [ ] Send OTA: `pio run -e esp32-c3-ota -t upload --upload-port <IP>`
6. [ ] Wait for reboot; validate version / behavior

Tip: keep a finger on the button and click again if idle is about to expire **before** starting the upload (do not click mid-transfer).

---

## Troubleshooting

| Symptom | Likely cause | What to do |
|---|---|---|
| `No such option: --upload-protocol` | Invalid flag on `pio run` | Use `-e esp32-c3-ota` (Method 1) |
| `No response` / timeout | Device sleeping | Wake with button; increase sleep delay; retry upload quickly |
| `Authentication Failed` | Wrong password | Check portal and `upload_flags` in ini |
| Host does not resolve (`.local`) | mDNS on Windows | Use numeric **IP** |
| PC and ESP on different networks | Guest Wi‑Fi / VLAN | Same SSID / same subnet |
| USB upload OK, OTA not | Partition without OTA | Flash USB with this project (`min_spiffs.csv`) |
| OTA starts then fails mid-way | Idle expired / weak Wi‑Fi | Larger sleep delay; move closer to AP |

ArduinoOTA error codes on Serial (`[ota] error N`):

| Code | Meaning |
|---|---|
| 0 | OTA_AUTH_ERROR — password |
| 1 | OTA_BEGIN_ERROR |
| 2 | OTA_CONNECT_ERROR |
| 3 | OTA_RECEIVE_ERROR |
| 4 | OTA_END_ERROR |

---

## First flash (USB)

OTA does **not** replace the first flash. Use a USB-C cable:

```bash
pio run -e esp32-c3-supermini -t upload --upload-port COMx
```

After that, updates can be OTA-only.

## Security

- Change the default OTA password in the portal on shared networks.
- OTA only on LAN; do not expose the port to the internet.
- Password is stored in ESP NVS (same namespace as Wi‑Fi/MQTT config).

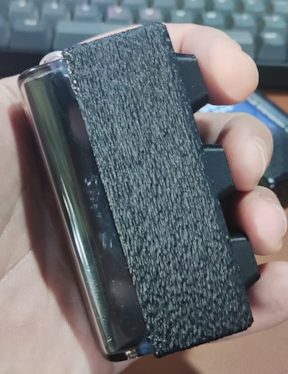
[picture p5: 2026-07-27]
DOC/pictures/HAButton_front_hand_p.png

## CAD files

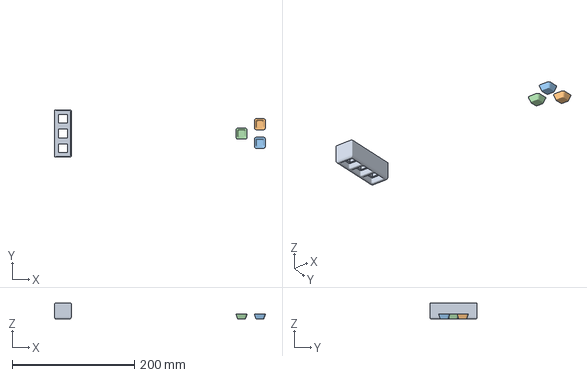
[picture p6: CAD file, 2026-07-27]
DOC/pictures/habutton_G30kpro.3mf
345.1 x 77.6 x 26.0 mm
ESP32C3Buttons.stl
Grand Stantia-Jofo (14).stl x 3

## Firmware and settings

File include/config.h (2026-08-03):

#pragma once

#if __has_include("secrets.h")
#include "secrets.h"
#endif

// ---------------------------------------------------------------------------
// Hardware — ESP32-C3 Super Mini
// ---------------------------------------------------------------------------
#ifndef BTN_A_PIN
#define BTN_A_PIN 4
#endif

#ifndef BTN_B_PIN
#define BTN_B_PIN 5
#endif

// Deep-sleep wake no C3: somente GPIO0–5 (RTC). GPIO6+ não acordam.
#ifndef BTN_C_PIN
#define BTN_C_PIN 3
#endif

#ifndef STATUS_LED_PIN
#define STATUS_LED_PIN 8
#endif

#ifndef STATUS_LED_ACTIVE_LOW
#define STATUS_LED_ACTIVE_LOW 1
#endif

// Pino de efeito externo (PWM ~0→2,5 V durante MQTT).
#ifndef EFFECT_PIN
#define EFFECT_PIN 7
#endif

#ifndef EFFECT_PWM_CHANNEL
#define EFFECT_PWM_CHANNEL 0
#endif

#ifndef EFFECT_PWM_FREQ_HZ
#define EFFECT_PWM_FREQ_HZ 5000
#endif

#ifndef EFFECT_PWM_RES_BITS
#define EFFECT_PWM_RES_BITS 10
#endif

#ifndef EFFECT_TARGET_MV
#define EFFECT_TARGET_MV 2500
#endif

#ifndef EFFECT_SUPPLY_MV
#define EFFECT_SUPPLY_MV 3300
#endif

// Tempo mínimo em 2,5 V após ligar o efeito (além de esperar o publish MQTT).
#ifndef EFFECT_HOLD_MIN_MS
#define EFFECT_HOLD_MIN_MS 500
#endif

// Gestos
#ifndef LONG_PRESS_MS
#define LONG_PRESS_MS 800
#endif

#ifndef CONFIG_CHORD_HOLD_MS
#define CONFIG_CHORD_HOLD_MS 10000
#endif

#ifndef BUTTON_CHORD_WINDOW_MS
#define BUTTON_CHORD_WINDOW_MS 100
#endif

#ifndef WIFI_PORTAL_FORCED_TIMEOUT_S
#define WIFI_PORTAL_FORCED_TIMEOUT_S 180
#endif

// ---------------------------------------------------------------------------
// WiFiManager
// ---------------------------------------------------------------------------
#ifndef WM_AP_NAME_PREFIX
#define WM_AP_NAME_PREFIX "HAButton"
#endif

#ifndef WIFI_CONNECT_TIMEOUT_S
#define WIFI_CONNECT_TIMEOUT_S 50
#endif

#ifndef WIFI_PORTAL_TIMEOUT_S
#define WIFI_PORTAL_TIMEOUT_S 90
#endif

// ---------------------------------------------------------------------------
// MQTT / Home Assistant — defaults
// ---------------------------------------------------------------------------
#ifndef DEFAULT_MQTT_HOST
#define DEFAULT_MQTT_HOST "homeassistant.local"
#endif

#ifndef DEFAULT_MQTT_PORT
#define DEFAULT_MQTT_PORT "1883"
#endif

#ifndef DEFAULT_MQTT_USER
#define DEFAULT_MQTT_USER ""
#endif

#ifndef DEFAULT_MQTT_PASS
#define DEFAULT_MQTT_PASS ""
#endif

#ifndef DEFAULT_MQTT_PREFIX
#define DEFAULT_MQTT_PREFIX "homeassistant"
#endif

#ifndef DEFAULT_DEVICE_NAME
#define DEFAULT_DEVICE_NAME "habutton"
#endif

#ifndef DEFAULT_BTN_A_NAME
#define DEFAULT_BTN_A_NAME "Botao A"
#endif

#ifndef DEFAULT_BTN_B_NAME
#define DEFAULT_BTN_B_NAME "Botao B"
#endif

#ifndef DEFAULT_BTN_C_NAME
#define DEFAULT_BTN_C_NAME "Botao C"
#endif

#ifndef DEFAULT_SLEEP_DELAY_MS
#define DEFAULT_SLEEP_DELAY_MS "20000"
#endif

#ifndef SLEEP_DELAY_MIN_MS
#define SLEEP_DELAY_MIN_MS 1000
#endif

#ifndef SLEEP_DELAY_MAX_MS
#define SLEEP_DELAY_MAX_MS 300000
#endif

#ifndef DEFAULT_OTA_PASS
#define DEFAULT_OTA_PASS "habutton-ota"
#endif

#ifndef DEFAULT_DEBUG_MQTT
#define DEFAULT_DEBUG_MQTT "0"
#endif

#ifndef DEFAULT_LONG_PRESS_MS
#define DEFAULT_LONG_PRESS_MS "800"
#endif

#ifndef DEFAULT_EFFECT_HOLD_MS
#define DEFAULT_EFFECT_HOLD_MS "500"
#endif

#ifndef DEFAULT_EFFECT_TARGET_MV
#define DEFAULT_EFFECT_TARGET_MV "2500"
#endif

#ifndef DEFAULT_EFFECT_MIRROR_LED
#define DEFAULT_EFFECT_MIRROR_LED "0"
#endif

#ifndef MQTT_CONNECT_TIMEOUT_MS
#define MQTT_CONNECT_TIMEOUT_MS 8000
#endif

#ifndef NVS_NAMESPACE
#define NVS_NAMESPACE "habutton"
#endif

#ifndef FW_VERSION
#define FW_VERSION "1.4.5"
#endif

// Incrementar ao mudar o schema de discovery MQTT (força limpeza + republicação).
// 10 = rediscovery confiável + birth HA (homeassistant/status).
#ifndef DISCOVERY_SCHEMA_VERSION
#define DISCOVERY_SCHEMA_VERSION 10
#endif

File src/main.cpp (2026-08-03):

#include <Arduino.h>
#include <WiFi.h>
#include <esp_sleep.h>

#include "buttons.h"
#include "config.h"
#include "effect_out.h"
#include "mqtt_ha.h"
#include "ota_update.h"
#include "serial_boot.h"
#include "status_led.h"
#include "wifi_setup.h"

namespace {

bool g_effectOn = false;
uint32_t g_effectAtTargetMs = 0;

String otaHostname(const AppConfig& cfg) {
  uint8_t mac[6];
  WiFi.macAddress(mac);
  char buf[48];
  snprintf(buf, sizeof(buf), "%s-%02x%02x", cfg.deviceName.c_str(), mac[4], mac[5]);
  return String(buf);
}

void effectPulseOn() {
  effectOutRampToTarget();
  g_effectOn = true;
  g_effectAtTargetMs = millis();
}

void effectPulseOff(const AppConfig& cfg) {
  if (!g_effectOn) {
    return;
  }
  const uint32_t holdMin = cfg.effectHoldMsValue();
  const uint32_t elapsed = millis() - g_effectAtTargetMs;
  if (elapsed < holdMin) {
    delay(holdMin - elapsed);
  }
  effectOutOff();
  g_effectOn = false;
}

void effectForceOff() {
  effectOutOff();
  g_effectOn = false;
}

// Fluxo: GPIO7 ON -> publish MQTT -> hold min -> GPIO7 OFF.
// Com mirror LED→effect ativo, o GPIO7 só segue o LED azul.
void publishWithEffect(AppConfig& cfg, const char* eventType) {
  if (eventType == nullptr || eventType[0] == '\0') {
    return;
  }
  const bool mirror = cfg.effectMirrorLedEnabled();
  if (!mirror) {
    effectPulseOn();
  }
  mqttPublishGesture(cfg, eventType);
  if (!mirror) {
    effectPulseOff(cfg);
  }
}

void logBootPinStates() {
  // Não remapeia GPIO8 (LED): só lê sem mudar pinMode do status LED.
  const int pins[] = {0, 2, 3, 4, 5, 9};
  Serial.print("[boot] niveis GPIO ");
  for (int pin : pins) {
    pinMode(pin, INPUT);
    Serial.printf("%d=%d ", pin, digitalRead(pin));
  }
  Serial.printf("8(led)=%d ", digitalRead(STATUS_LED_PIN));
  Serial.println();
}

}  // namespace

void setup() {
  serialBootBegin();
  logBootPinStates();

  statusLedBegin();
  statusLedOn();

  effectOutBegin();
  buttonsBegin();

  const bool wokeByGpio =
      (esp_sleep_get_wakeup_cause() == ESP_SLEEP_WAKEUP_GPIO);

  // Identifica o botao do wake ANTES do Wi-Fi (GPIO7 ainda off).
  const char* wakeEvent = nullptr;
  if (wokeByGpio || buttonsAnyDown()) {
    wakeEvent = buttonsCaptureWakePress();
    Serial.printf("[main] wake mask/event=%s\n",
                  wakeEvent != nullptr ? wakeEvent : "(nenhum)");
  }

  delay(30);
  // LED permanece aceso na inicialização até o Wi‑Fi assumir o modo (pisca/portal).
  Serial.println();
  Serial.printf("=== HAButton ESP32-C3 %s ===\n", FW_VERSION);
  Serial.printf("[main] wake=%s btn_down=%d\n", wokeByGpio ? "GPIO" : "outro",
                buttonsAnyDown() ? 1 : 0);

  AppConfig cfg;
  const bool wifiOk = wifiSetupAndConnect(cfg);
  if (!wifiOk) {
    Serial.println("[main] Wi-Fi indisponivel; indo dormir");
    statusLedOff();
    effectForceOff();
    WiFi.disconnect(true, false);
    WiFi.mode(WIFI_OFF);
    enterDeepSleep();
    return;
  }

  otaBegin(otaHostname(cfg), cfg.otaPass);

  if (!mqttEnsureConnected(cfg)) {
    Serial.println("[main] MQTT indisponivel; sessao curta sem broker");
  } else {
    char detail[96];
    snprintf(detail, sizeof(detail), "wake=%s event=%s ip=%s",
             wokeByGpio ? "gpio" : "other",
             wakeEvent != nullptr ? wakeEvent : "none",
             WiFi.localIP().toString().c_str());
    mqttPublishLog(cfg, "session_start", detail);
  }

  // Publica o gesto que acordou: ON GPIO7 -> MQTT -> OFF GPIO7.
  if (wakeEvent != nullptr) {
    publishWithEffect(cfg, wakeEvent);
    buttonsWaitReleaseAndReset();
  } else {
    buttonsWaitReleaseAndReset();
  }

  // Sessão idle: LED pisca lento; pulsos rápidos em publish MQTT.
  statusLedSetMode(StatusLedMode::BlinkIdle);
  uint32_t idleDeadline = millis() + cfg.sleepDelayMsValue();
  Serial.printf("[main] sessao acordada idle=%u ms debug=%d\n",
                cfg.sleepDelayMsValue(), cfg.debugMqttEnabled() ? 1 : 0);

  bool sleepWarned = false;

  while (millis() < idleDeadline) {
    statusLedTick();
    otaHandle();
    mqttHandle(cfg);

    if (otaIsInProgress()) {
      idleDeadline = millis() + cfg.sleepDelayMsValue();
      sleepWarned = false;
      delay(5);
      continue;
    }

    mqttEnsureConnected(cfg);

    const uint32_t remain = (idleDeadline > millis()) ? (idleDeadline - millis()) : 0;
    if (!sleepWarned && remain > 0 && remain <= 2000) {
      sleepWarned = true;
      mqttPublishLog(cfg, "sleep_soon", "idle_expiring");
      Serial.println("[main] idle quase esgotado — sleep em breve");
    }

    const GestureResult g = buttonsPollGesture();

    if (g.isConfigChord) {
      Serial.println("[main] config chord — reiniciando no portal");
      mqttPublishLog(cfg, "portal_request", "abc_10s");
      wifiRequestConfigPortalOnNextBoot();
      effectForceOff();
      statusLedOff();
      delay(100);
      ESP.restart();
    }

    if (g.isRediscoverChord) {
      Serial.println("[main] A+C 10s — republicando discovery/config MQTT");
      statusLedOn();
      const bool ok = mqttRepublishAll(cfg);
      Serial.printf("[main] rediscover -> %s\n", ok ? "ok" : "FAIL");
      buttonsWaitReleaseAndReset();
      statusLedSetMode(StatusLedMode::BlinkIdle);
      idleDeadline = millis() + cfg.sleepDelayMsValue();
      sleepWarned = false;
      continue;
    }

    // Proximos acionamentos na sessao: identifica no release, depois GPIO7+MQTT+OFF.
    if (g.hasEvent && g.eventType != nullptr) {
      publishWithEffect(cfg, g.eventType);
      idleDeadline = millis() + cfg.sleepDelayMsValue();
      sleepWarned = false;
      Serial.printf("[main] idle reset -> %u ms\n", cfg.sleepDelayMsValue());
    }

    delay(5);
  }

  Serial.println("[main] idle esgotado — deep sleep");
  mqttPublishLog(cfg, "sleep_enter", "idle_timeout");
  delay(80);
  statusLedOff();
  effectForceOff();
  mqttDisconnect();
  WiFi.disconnect(true, false);
  WiFi.mode(WIFI_OFF);
  enterDeepSleep();
}

void loop() {
  // Deep sleep no setup.
}

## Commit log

2026-07-24 Initial commit: ESP32-C3 HAButton with MQTT Home Assistant discovery.
    Firmware for deep-sleep GPIO wake, WiFiManager portal, and dual mechanical switches.
2026-07-24 Enhance MQTT Home Assistant integration and configuration. Updated discovery topics to comply with HA requirements, ensuring mandatory prefix usage. Improved timeout settings and refined documentatio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
    [config.h, mqtt_ha.cpp, wifi_setup.cpp]
2026-07-24 Refine MQTT Home Assistant integration with updated discovery topics and event handling. Introduced single-component discovery format, clarified documentation on topic usage, and added support for on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
2026-07-26 Update firmware to version 1.3.2, enhancing button handling and MQTT event publishing. Added support for a third button, refined gesture detection logic, and improved deep sleep management. Updated d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
2026-07-27 Update firmware to version 1.4.2, introducing enhanced button handling, improved MQTT event publishing, and refined configuration options. Added support for OTA updates via LAN with a dedicated envir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
2026-07-27 Update documentation to include a new project description for repurposing used vaporizers into MQTT-enabled devices for Home Assistant integration. Added details on device functionality, including bu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
2026-07-27 Update README files to enhance project documentation for repurposing used vaporizers. Added detailed descriptions of device functionality, including ESP32-C3 integration, button handling, Wi-Fi setup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
2026-07-27 Add images to README for enhanced project visualization
    [habutton_G30kpro.3mf]
2026-07-27 Update README files to include links for 3D printed case models. Enhanced component list in both English and Portuguese versions for clarity and accessibility.
2026-07-27 Fix links in README files for 3D printed case models to ensure correct file paths in both English and Portuguese versions. This improves accessibility and clarity for users.
2026-07-27 Update README files to correct minor formatting inconsistencies in links for 3D printed case models in both English and Portuguese versions, ensuring clarity and accessibility for users.
2026-07-27 Insert Home Assistant image in README
    Added image of Home Assistant to the README.
2026-08-03 Update documentation to reflect firmware version change to 1.4.5 and enhance MQTT topic descriptions. Added support for LED mirroring functionality and improved configuration handling for effect sett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
